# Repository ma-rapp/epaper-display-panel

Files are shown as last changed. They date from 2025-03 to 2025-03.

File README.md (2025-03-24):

# ePaper Display Panel

This package contains the code to control an ePaper panel.
The display is organized in separate apps.
Each app can display several screens.

The screen images are rendered on a server and simply downloaded for display.
That allows to keep this module as lean as possible, as this is running on a Raspberry Pi Zero 2W.
For the server, see [epaper-display-server](https://github.com/ma-rapp/epaper-display-server).

The panel supports two buttons, where the left button switches between apps and the right button switches screen within the current app.

## Installation

Tested on Raspberry Pi OS Lite.

To set up:
1. Configure server url in `config.yaml`
2. Configure paths in `panel.service`
3. Install required packages
    ```bash
    sudo apt install libgpiod-dev libsystemd-dev swig
    ```
4. Install uv
5. Setup virtual environment
    ```bash
    uv sync --no-dev
    ```
6. Enable service
    ```bash
    loginctl enable-linger pi

    systemctl --user link /home/pi/projects/epaper-display-panel/panel.service
    systemctl --user enable panel
    systemctl --user start panel
    ```
7. Setup periodic tasks
    ```bash
    crontab -e
    ```
    Add following entry to:
    - check for updates to the environment every day
    ```
    1 1 * * * (date && cd ~/projects/epaper-display-panel && /home/pi/.local/bin/uv lock --upgrade) >> ~/projects/epaper-display-panel/logs/uv-update.log 2>&1
    ```

To disable the service:
1. Run
    ```
    systemctl --user stop panel
    systemctl --user disable panel
    ```

## Development

```
uv sync --dev
uv run pre-commit install
```

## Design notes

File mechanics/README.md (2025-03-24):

# Overview of printed parts

| Printed part | Count | Notes |
|---|---|---|
| adapter-mount.stl  | 1 | |
| back.stl | 1 | |
| front.stl | 1 | add 14 heat set inserts M3 |
| mount.stl | 2 | |
| panel-clamp.stl | 3 | glue some foam to it |
| pi-mount-a.stl | 1 | |
| pi-mount-b.stl | 1 | |
| switch-mount-a.stl | 1 | |
| switch-mount-b.stl | 1 | |
| switch.stl | 2 | may need adjustment of the height to fit the switch |

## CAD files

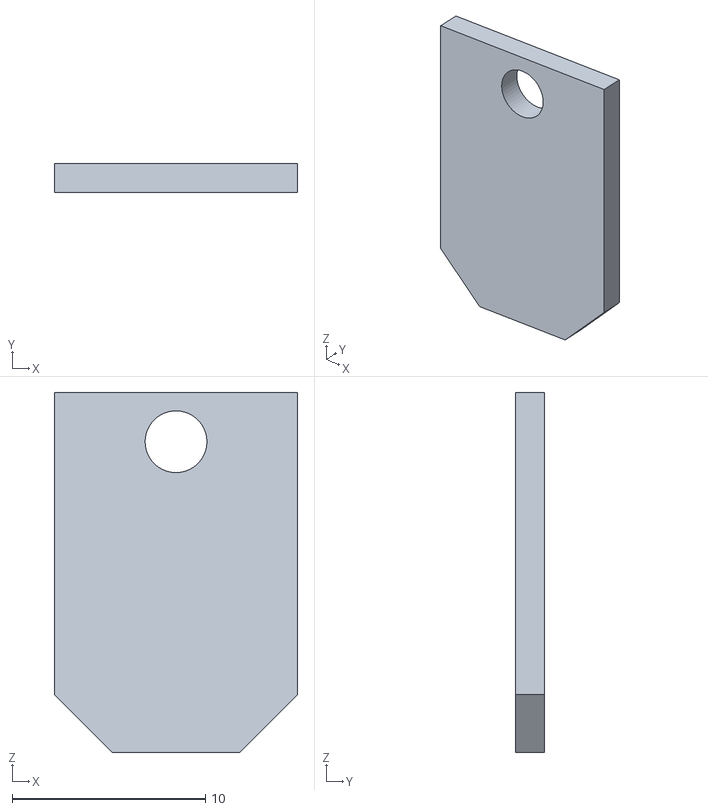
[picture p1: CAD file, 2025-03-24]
mechanics/panel-clamp.stl
12.6 x 1.50 x 18.7

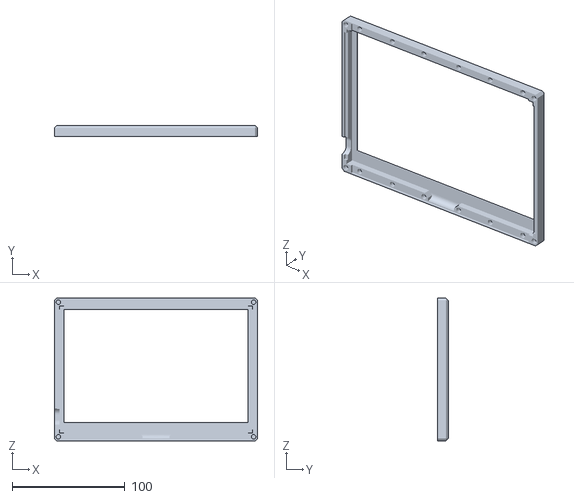
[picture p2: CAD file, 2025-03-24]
mechanics/front.stl
180.0 x 9.50 x 126.4

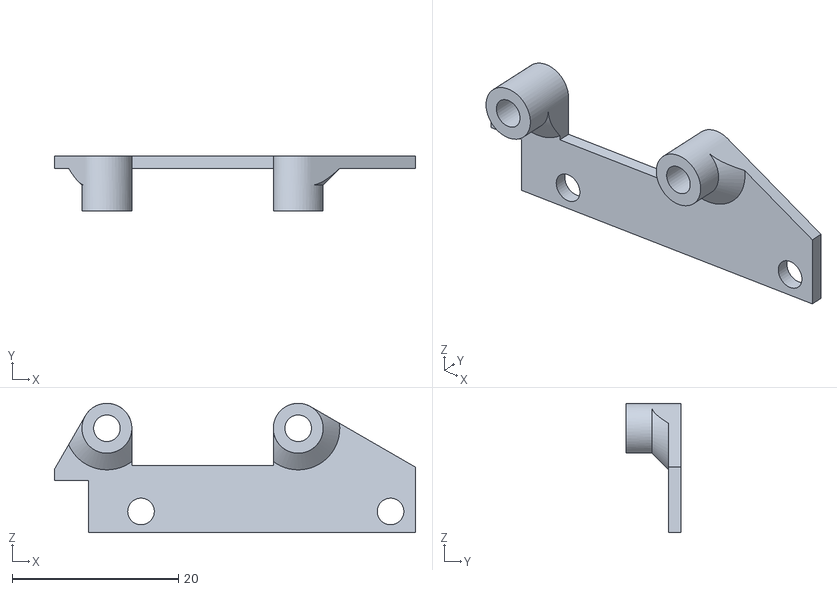
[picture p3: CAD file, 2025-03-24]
mechanics/pi-mount-a.stl
43.4 x 6.60 x 15.5

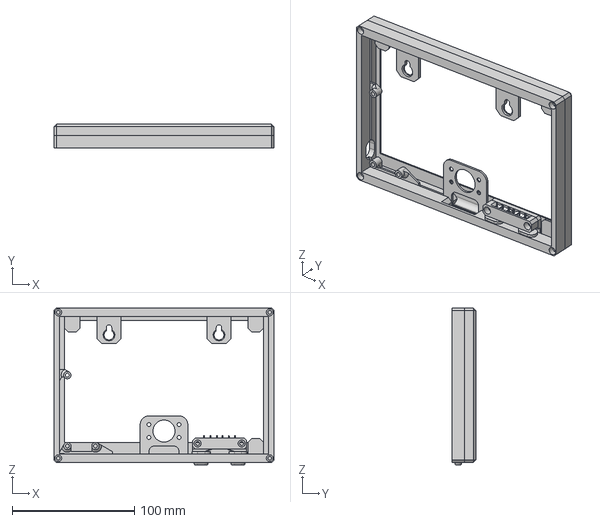
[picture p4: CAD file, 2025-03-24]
mechanics/panel.step
180.0 x 19.5 x 128.4 mm
Taster x 2

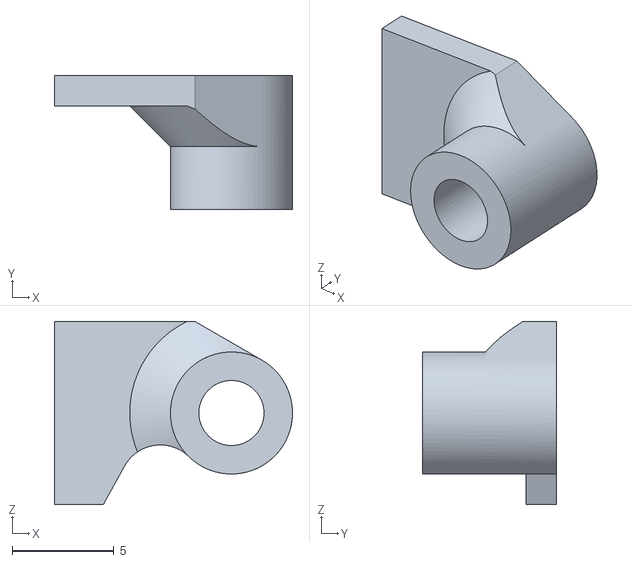
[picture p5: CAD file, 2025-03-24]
mechanics/pi-mount-b.stl
11.7 x 6.60 x 9.00

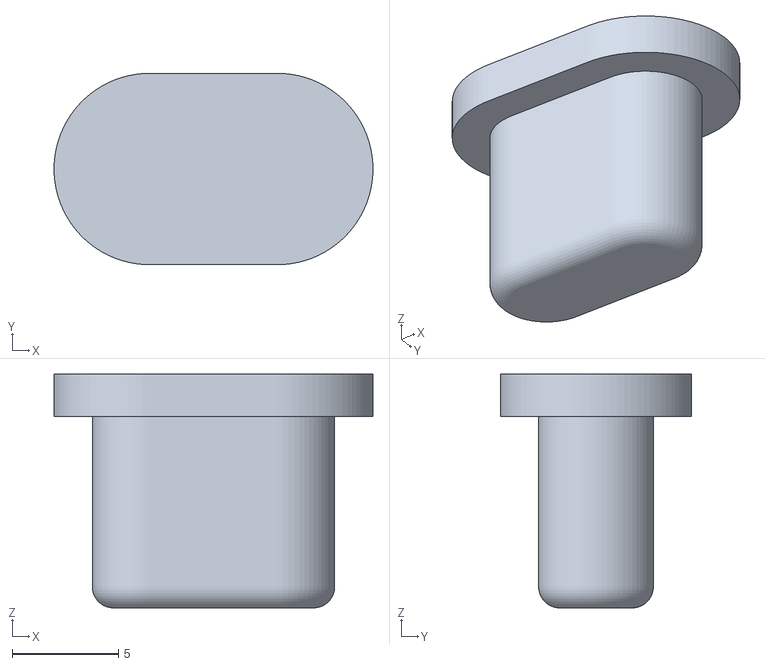
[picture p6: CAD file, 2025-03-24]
mechanics/switch.stl
15.0 x 9.00 x 11.0

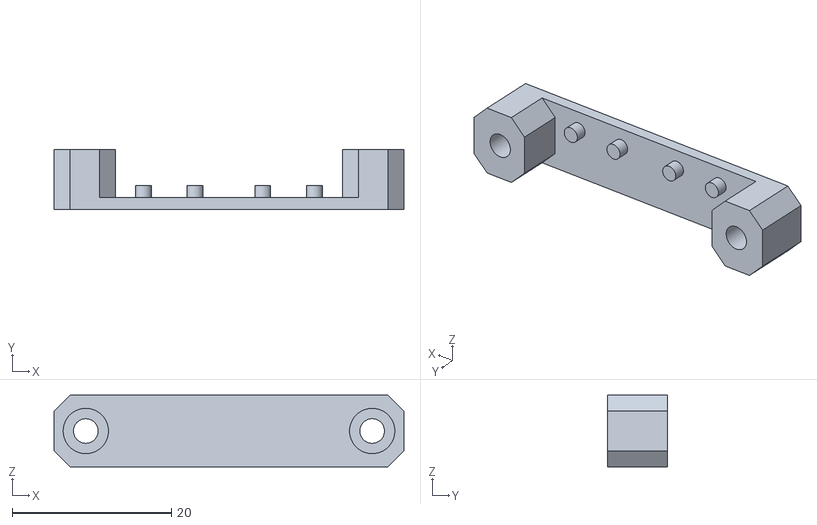
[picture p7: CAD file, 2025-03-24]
mechanics/switch-mount-b.stl
44.0 x 7.50 x 9.00

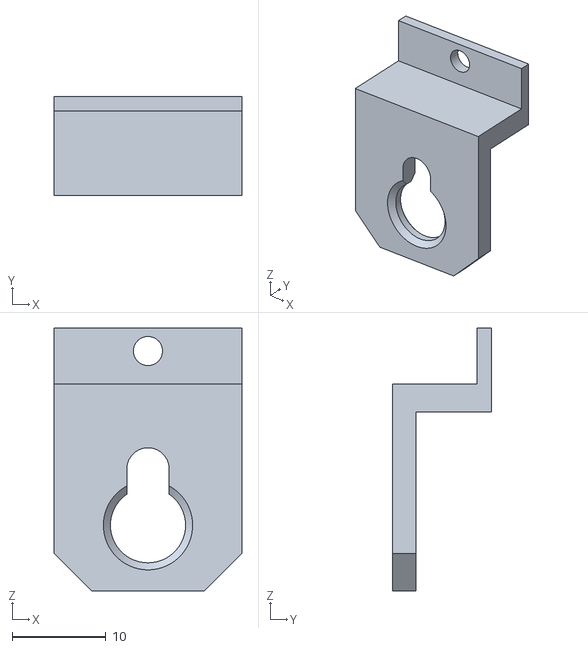
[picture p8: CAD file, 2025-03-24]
mechanics/mount.stl
20.0 x 10.5 x 28.0

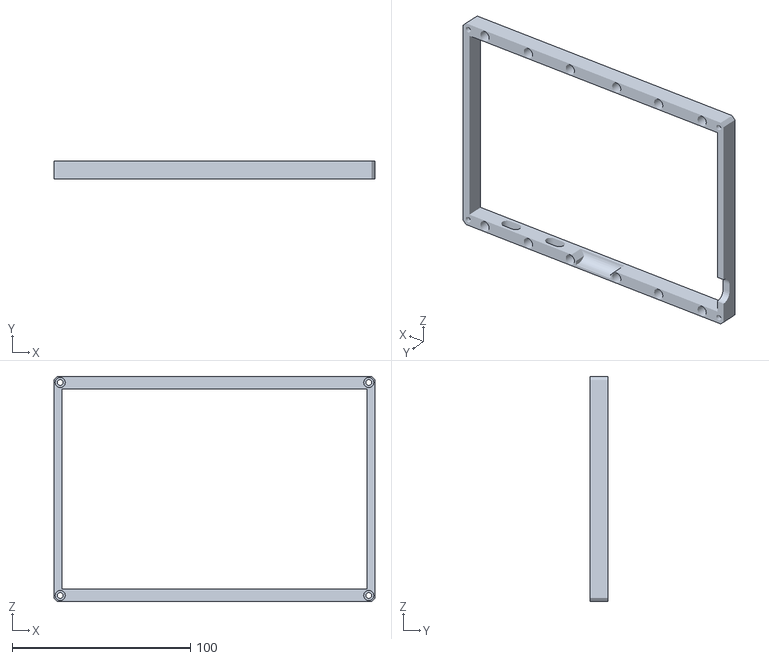
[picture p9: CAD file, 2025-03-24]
mechanics/back.stl
180.0 x 10.0 x 126.4

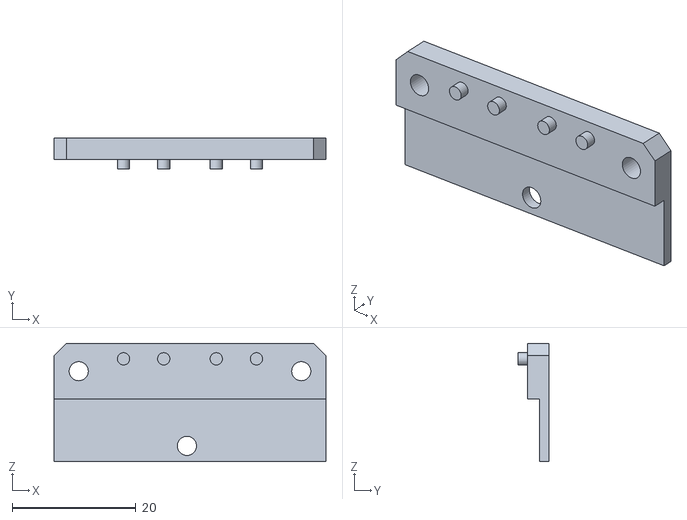
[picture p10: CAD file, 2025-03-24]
mechanics/switch-mount-a.stl
44.0 x 5.00 x 19.1

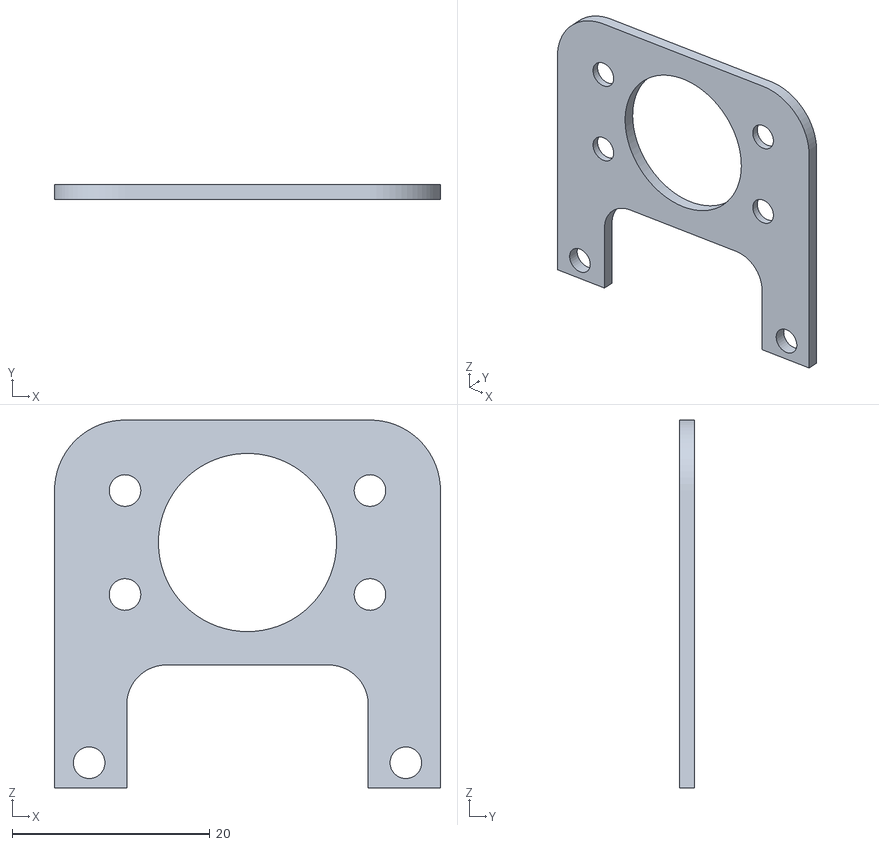
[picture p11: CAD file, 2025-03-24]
mechanics/adapter-mount.stl
39.0 x 1.50 x 37.2

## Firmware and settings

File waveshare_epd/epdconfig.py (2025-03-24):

# This file is a modified version of the original epdconfig.py file from the Waveshare e-Paper display library.
#
# original license:
#
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

import logging
import os
import time
from ctypes import CDLL

import gpiozero
import spidev

logger = logging.getLogger(__name__)


class RaspberryPi:
    # Pin definition
    RST_PIN = 17
    DC_PIN = 25
    CS_PIN = 8
    BUSY_PIN = 24
    PWR_PIN = 18
    MOSI_PIN = 10
    SCLK_PIN = 11

    def __init__(self):
        self.SPI = spidev.SpiDev()
        self.GPIO_RST_PIN = gpiozero.LED(self.RST_PIN)
        self.GPIO_DC_PIN = gpiozero.LED(self.DC_PIN)
        # self.GPIO_CS_PIN     = gpiozero.LED(self.CS_PIN)
        self.GPIO_PWR_PIN = gpiozero.LED(self.PWR_PIN)
        self.GPIO_BUSY_PIN = gpiozero.Button(self.BUSY_PIN, pull_up=False)

    def digital_write(self, pin, value):
        if pin == self.RST_PIN:
            if value:
                self.GPIO_RST_PIN.on()
            else:
                self.GPIO_RST_PIN.off()
        elif pin == self.DC_PIN:
            if value:
                self.GPIO_DC_PIN.on()
            else:
                self.GPIO_DC_PIN.off()
        # elif pin == self.CS_PIN:
        #     if value:
        #         self.GPIO_CS_PIN.on()
        #     else:
        #         self.GPIO_CS_PIN.off()
        elif pin == self.PWR_PIN:
            if value:
                self.GPIO_PWR_PIN.on()
            else:
                self.GPIO_PWR_PIN.off()

    def digital_read(self, pin):
        if pin == self.BUSY_PIN:
            return self.GPIO_BUSY_PIN.value
        elif pin == self.RST_PIN:
            return self.RST_PIN.value
        elif pin == self.DC_PIN:
            return self.DC_PIN.value
        # elif pin == self.CS_PIN:
        #     return self.CS_PIN.value
        elif pin == self.PWR_PIN:
            return self.PWR_PIN.value

    def delay_ms(self, delaytime):
        time.sleep(delaytime / 1000.0)

    def spi_writebyte(self, data):
        self.SPI.writebytes(data)

    def spi_writebyte2(self, data):
        self.SPI.writebytes2(data)

    def DEV_SPI_write(self, data):
        self.DEV_SPI.DEV_SPI_SendData(data)

    def DEV_SPI_nwrite(self, data):
        self.DEV_SPI.DEV_SPI_SendnData(data)

    def DEV_SPI_read(self):
        return self.DEV_SPI.DEV_SPI_ReadData()

    def module_init(self, cleanup=False):
        self.GPIO_PWR_PIN.on()

        if cleanup:
            find_dirs = [
                os.path.dirname(os.path.realpath(__file__)),
                "/usr/local/lib",
                "/usr/lib",
            ]
            self.DEV_SPI = None
            for find_dir in find_dirs:
                val = int(os.popen("getconf LONG_BIT").read())
                logging.debug("System is %d bit" % val)
                if val == 64:
                    so_filename = os.path.join(find_dir, "DEV_Config_64.so")
                else:
                    so_filename = os.path.join(find_dir, "DEV_Config_32.so")
                if os.path.exists(so_filename):
                    self.DEV_SPI = CDLL(so_filename)
                    break
            if self.DEV_SPI is None:
                RuntimeError("Cannot find DEV_Config.so")

            self.DEV_SPI.DEV_Module_Init()

        else:
            # SPI device, bus = 0, device = 0
            self.SPI.open(0, 0)
            self.SPI.max_speed_hz = 4000000
            self.SPI.mode = 0b00
        return 0

    def module_exit(self, cleanup=False):
        logger.debug("spi end")
        self.SPI.close()

        self.GPIO_RST_PIN.off()
        self.GPIO_DC_PIN.off()
        self.GPIO_PWR_PIN.off()
        logger.debug("close 5V, Module enters 0 power consumption ...")

        if cleanup:
            self.GPIO_RST_PIN.close()
            self.GPIO_DC_PIN.close()
            # self.GPIO_CS_PIN.close()
            self.GPIO_PWR_PIN.close()
            self.GPIO_BUSY_PIN.close()

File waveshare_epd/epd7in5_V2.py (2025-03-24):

# This file is a modified version of the original epd7in5.py file from the Waveshare e-Paper display driver.
#
# original license:
#
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


import logging

# Display resolution
EPD_WIDTH = 800
EPD_HEIGHT = 480

GRAY1 = 0xFF  # white
GRAY2 = 0xC0
GRAY3 = 0x80  # gray
GRAY4 = 0x00  # Blackest

logger = logging.getLogger(__name__)


class EPD:
    def __init__(self, epdconfig):
        self.epdconfig = epdconfig
        self.reset_pin = self.epdconfig.RST_PIN
        self.dc_pin = self.epdconfig.DC_PIN
        self.busy_pin = self.epdconfig.BUSY_PIN
        self.cs_pin = self.epdconfig.CS_PIN
        self.width = EPD_WIDTH
        self.height = EPD_HEIGHT
        self.GRAY1 = GRAY1  # white
        self.GRAY2 = GRAY2
        self.GRAY3 = GRAY3  # gray
        self.GRAY4 = GRAY4  # Blackest

    # Hardware reset
    def reset(self):
        self.epdconfig.digital_write(self.reset_pin, 1)
        self.epdconfig.delay_ms(20)
        self.epdconfig.digital_write(self.reset_pin, 0)
        self.epdconfig.delay_ms(2)
        self.epdconfig.digital_write(self.reset_pin, 1)
        self.epdconfig.delay_ms(20)

    def send_command(self, command):
        self.epdconfig.digital_write(self.dc_pin, 0)
        self.epdconfig.digital_write(self.cs_pin, 0)
        self.epdconfig.spi_writebyte([command])
        self.epdconfig.digital_write(self.cs_pin, 1)

    def send_data(self, data):
        self.epdconfig.digital_write(self.dc_pin, 1)
        self.epdconfig.digital_write(self.cs_pin, 0)
        self.epdconfig.spi_writebyte([data])
        self.epdconfig.digital_write(self.cs_pin, 1)

    def send_data2(self, data):
        self.epdconfig.digital_write(self.dc_pin, 1)
        self.epdconfig.digital_write(self.cs_pin, 0)
        self.epdconfig.SPI.writebytes2(data)
        self.epdconfig.digital_write(self.cs_pin, 1)

    def ReadBusy(self):
        logger.debug("e-Paper busy")
        self.send_command(0x71)
        busy = self.epdconfig.digital_read(self.busy_pin)
        while busy == 0:
            self.send_command(0x71)
            busy = self.epdconfig.digital_read(self.busy_pin)
        self.epdconfig.delay_ms(20)
        logger.debug("e-Paper busy release")

    def init(self):
        if self.epdconfig.module_init() != 0:
            return -1
        # EPD hardware init start
        self.reset()

        self.send_command(0x06)  # btst
        self.send_data(0x17)
        self.send_data(0x17)
        self.send_data(0x28)  # If an exception is displayed, try using 0x38
        self.send_data(0x17)

        self.send_command(0x01)  # POWER SETTING
        self.send_data(0x07)
        self.send_data(0x07)  # VGH=20V,VGL=-20V
        self.send_data(0x28)  # VDH=15V
        self.send_data(0x17)  # VDL=-15V

        self.send_command(0x04)  # POWER ON
        self.epdconfig.delay_ms(100)
        self.ReadBusy()

        self.send_command(0x00)  # PANNEL SETTING
        self.send_data(0x1F)  # KW-3f   KWR-2F	BWROTP 0f	BWOTP 1f

        self.send_command(0x61)  # tres
        self.send_data(0x03)  # source 800
        self.send_data(0x20)
        self.send_data(0x01)  # gate 480
        self.send_data(0xE0)

        self.send_command(0x15)
        self.send_data(0x00)

        # If the screen appears gray, use the annotated initialization command
        self.send_command(0x50)
        self.send_data(0x10)
        self.send_data(0x07)
        # self.send_command(0X50)
        # self.send_data(0x10)
        # self.send_data(0x17)
        # self.send_command(0X52)
        # self.send_data(0x03)

        self.send_command(0x60)  # TCON SETTING
        self.send_data(0x22)

        # EPD hardware init end
        return 0

    def init_fast(self):
        if self.epdconfig.module_init() != 0:
            return -1
        # EPD hardware init start
        self.reset()

        self.send_command(0x00)  # PANNEL SETTING
        self.send_data(0x1F)  # KW-3f   KWR-2F	BWROTP 0f	BWOTP 1f

        # If the screen appears gray, use the annotated initialization command
        self.send_command(0x50)
        self.send_data(0x10)
        self.send_data(0x07)
        # self.send_command(0X50)
        # self.send_data(0x10)
        # self.send_data(0x17)
        # self.send_command(0X52)
        # self.send_data(0x03)

        self.send_command(0x04)  # POWER ON
        self.epdconfig.delay_ms(100)
        self.ReadBusy()  # waiting for the electronic paper IC to release the idle signal

        # Enhanced display drive(Add 0x06 command)
        self.send_command(0x06)  # Booster Soft Start
        self.send_data(0x27)
        self.send_data(0x27)
        self.send_data(0x18)
        self.send_data(0x17)

        self.send_command(0xE0)
        self.send_data(0x02)
        self.send_command(0xE5)
        self.send_data(0x5A)

        # EPD hardware init end
        return 0

    def init_part(self):
        if self.epdconfig.module_init() != 0:
            return -1
        # EPD hardware init start
        self.reset()

        self.send_command(0x00)  # PANNEL SETTING
        self.send_data(0x1F)  # KW-3f   KWR-2F	BWROTP 0f	BWOTP 1f

        self.send_command(0x04)  # POWER ON
        self.epdconfig.delay_ms(100)
        self.ReadBusy()  # waiting for the electronic paper IC to release the idle signal

        self.send_command(0xE0)
        self.send_data(0x02)
        self.send_command(0xE5)
        self.send_data(0x6E)

        # EPD hardware init end
        return 0

    # The feature will only be available on screens sold after 24/10/23
    def init_4Gray(self):
        if self.epdconfig.module_init() != 0:
            return -1
        # EPD hardware init start
        self.reset()

        self.send_command(0x00)  # PANNEL SETTING
        self.send_data(0x1F)  # KW-3f   KWR-2F	BWROTP 0f	BWOTP 1f

        self.send_command(0x50)
        self.send_data(0x10)
        self.send_data(0x07)

        self.send_command(0x04)  # POWER ON
        self.epdconfig.delay_ms(100)
        self.ReadBusy()  # waiting for the electronic paper IC to release the idle signal

        # Enhanced display drive(Add 0x06 command)
        self.send_command(0x06)  # Booster Soft Start
        self.send_data(0x27)
        self.send_data(0x27)
        self.send_data(0x18)
        self.send_data(0x17)

        self.send_command(0xE0)
        self.send_data(0x02)
        self.send_command(0xE5)
        self.send_data(0x5F)

        # EPD hardware init end
        return 0
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

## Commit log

2025-03-24 add printed parts
    [adapter-mount.stl, back.stl, front.stl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]
2025-04-06 make timeout configurable when to switch to next app automatically; sprinkle a few type hints
